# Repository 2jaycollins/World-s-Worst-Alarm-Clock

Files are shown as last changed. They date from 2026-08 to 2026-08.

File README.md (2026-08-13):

# The World's Worst Alarm Clock Ever

An ESP32 alarm clock that keeps perfect time, pulls the weather, works as a Bluetooth speaker, and most importantly, it is very unpredictable.

It is a genuinely good alarm clock. It syncs from NTP, it has a battery-backed RTC so a power cut doesn't touch it, it dims itself at night, and also has forty different ways of ruining your morning.

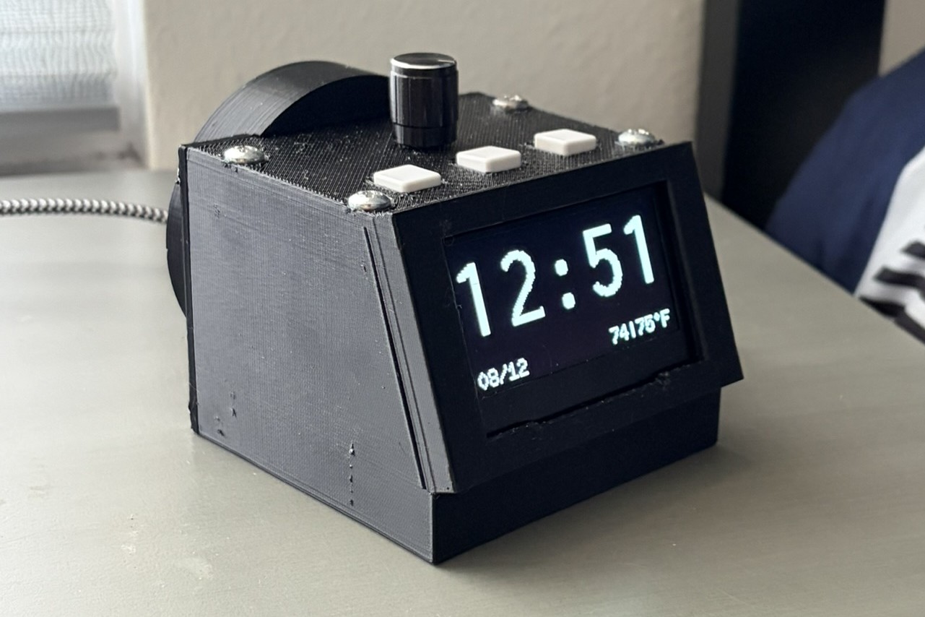
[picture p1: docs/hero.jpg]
The clock on a bedside table


**Demo video:** _(coming soon)_

---

## Why

My roommate needed a new alarm clock, so I took it upon myself to make his life as slightly inconvenient as I could. The problem with a normal alarm is that it works exactly how it is supposed to. Where is the fun in that? This alarm clock is packed with a variety of "features" that do anything from canceling your alarm for no reason to whispering at you in your sleep. 

---

## What it does

**Clock** — Battery-backed DS3231 corrected from NTP at boot. 12/24 hour, date, live temperature. 45 selectable clock fonts, cycled straight from the knob. Automatic night mode dims the panel at a set hour and strips the screen back to just the time. Four brightness levels driven by the SSD1309's real contrast, pre-charge and VCOMH registers, so it goes genuinely dark rather than just dim.

**Weather** — Current temperature and today's high from open-meteo, switching to tomorrow's high in the evening. Multiple saved locations with full POSIX timezone and DST rules; changing location re-syncs both the clock and the forecast. WiFi powers down between refreshes, and a reading that has failed to update several times running is marked stale rather than silently shown as current.

**Alarm** — Set from the menu or armed with one button on the clock face. Plays any WAV or MP3 from the on-board filesystem, and several can be chained into a sequence. The panel flashes while it rings, and a ring pulls the display out of night mode — then puts it back afterwards.

**Bluetooth speaker** — The clock is an A2DP sink. Track title and artist scroll along the bottom and freeze when you pause; the three front buttons become transport controls and the knob is volume. An alarm going off will drop the Bluetooth link, take the audio hardware back, and ring.

Bluetooth mode

---

## The trolls

Forty randomly-triggered events that range from quick visual gags to multi-hour long interruptions.

A troll in action

**Minor** gags are dismissed by any button — a school of fish swims across the clock, a figure paces the screen with footstep audio, the digits scroll too fast to read, the whole clock comes loose and drifts.

**Major** ones freeze the buttons. A firmware update that takes an hour and never finishes. A system error counting down in milliseconds to a reset that never comes. A self-destruct that strobes, detonates, and then leaves you looking at ten full seconds of dead screen wondering whether you've killed it — before the clock crawls back in from off-screen, one element at a time.

**Daily** moods are rolled each morning and last all day: a fish tank in front of the still-working clock, the entire display rotated 180°, or the clock shrunk to a tiny readout with the font control disabled.

**Weather scenes** track the real forecast — drizzle, rain, showers, snow and thunderstorms, each with its own particle density, fall speed, wind slant and animation cadence. When it's raining outside, it rains on your clock.

Storm scene

**Fundamentals** aren't events at all, they're permanent changes in behaviour. The snooze wheel replaces your snooze length with a slot machine. Snooze games make you win a minigame to earn one — lose, and the alarm switches off entirely and has to be re-armed by hand. Alarm drift moves the alarm up to ten minutes either way, re-rolled every time you arm it so the offset can't be learned.

There's a safety switch, accessible by a secret code, that allows the customization of the events and what they are capable of. That's the difference between something you can sleep next to and a science experiment.

---

## Engineering notes

Forty gags share one codebase without turning into forty special cases, mostly because trolls are treated as data rather than code. Each one is a row in a table — kind, duration, whether it draws over the clock, function pointers for its lifecycle hooks. Adding a new troll means an enum entry, a table row, and a draw function; the menu entry, saved on/off state, random scheduling, and input handling come for free. A static_assert catches it if the enum and table ever drift out of sync.

Trolls don't touch the clock state directly. They write to a set of hooks — fake times, per-element pixel offsets, layout flags — that get reset centrally whenever an event ends. That's what stops a cancelled or interrupted troll from leaving the clock in a broken state.

Animation is stateless. Every draw call works out where it is in the sequence as a fraction from 0 to 1 and renders from that alone — nothing increments a frame counter. That means frame rate doesn't matter, there's no state to clean up, and frame 900 renders correctly without stepping through the 899 before it.

Bluetooth and the sound engine fight over the same I2S peripheral, since only one driver can hold it at a time. Switching to speaker mode tears down the sound engine's driver and hands the pins to the A2DP sink; switching back reinstalls it, and an alarm that fires mid-Bluetooth-playback does that handoff live. Getting the Bluetooth stack to fit at all meant giving up the second OTA slot for a custom partition table.

It's a clock, so it has to behave like one even when things go wrong. It comes up on the RTC's last known time if there's no network at boot. Buttons are interrupt-driven with debounce handled in the ISR itself. State transitions are owned by a single file instead of being triggered piecemeal from whatever module wants one. If nobody touches it for a few days, it dims the display and suspends every troll until someone interacts with it again.

Every tunable value — pins, timeouts, night-mode hours, sound files and volumes, per-troll trigger odds, fish swim speed, blink frequency — lives in one config file, so behavior can be adjusted without touching the logic anywhere else.

Designing and printing the case was one of the most time consuming parts of the whole project. The measurements are extremely precise and it took multiple renditions to perfectly narrow down the design. The STL file is shown below.

Stack: C++ on ESP32 / Arduino via PlatformIO · U8g2 · ESP8266Audio · ESP32-A2DP · ArduinoJson · LittleFS · NVS · open-meteo

---

## Hardware

ESP32, SSD1309 128×64 SPI OLED, DS3231 RTC, rotary encoder, three buttons, and a MAX98357A I2S amplifier driving a small speaker.

## Parts list
- [ESP32 dev board](https://www.amazon.com/ESP-WROOM-32-Development-Dual-Mode-Microcontroller-Integrated/dp/B0BK13HWBJ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)
- [SSD1309 2.42" OLED (SPI version)](https://www.aliexpress.us/item/2255799816264653.html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)
- [KY-040 rotary encoder](https://www.aliexpress.us/item/3256807353813379.html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)
- [8Ω speaker](https://www.aliexpress.us/item/3256807619443281.html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)
- [DS3231 RTC module](https://www.aliexpress.us/item/3256805941102171.html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)
- [MAX 98357 amplifier](https://www.amazon.com/dp/B0DPJRLMDJ?ref=ppx_yo2ov_dt_b_fed_asin_title)
- [Buttons](https://www.amazon.com/20pcs-Momentary-Tactile-Button-Switch/dp/B008DGA9UY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)
## Printable enclosure (STL)
Preview on thingiverse (https://www.thingiverse.com/thing:7395218)

-Alternate download:
[STL file](docs/WorstAlarmClockEver.stl)

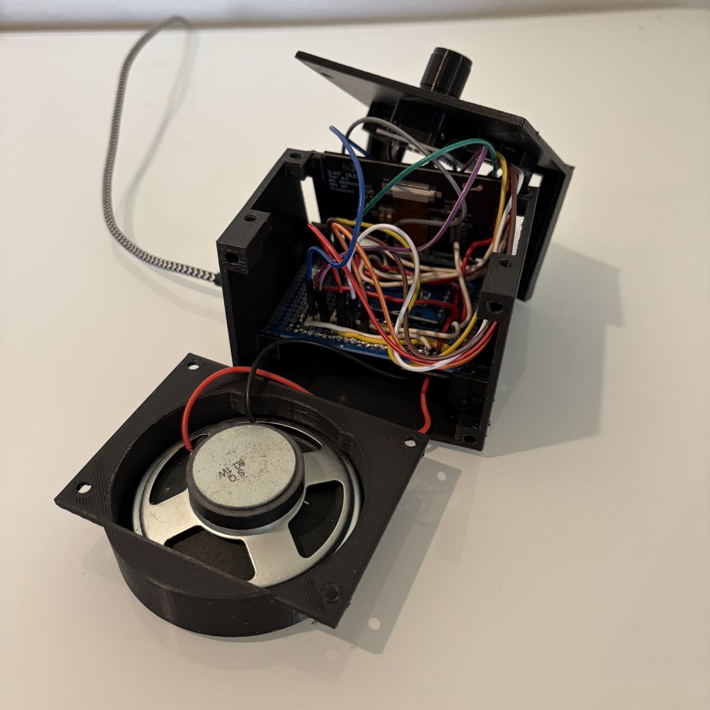
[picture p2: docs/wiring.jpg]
Wiring


---

## Code layout

```
include/values.h          every tunable number, in one place
src/application_code.cpp  main loop and every state transition
src/clock_logic.cpp       timekeeping, WiFi, weather
src/clock.cpp             clock face, brightness, night mode, fonts
src/alarm.cpp             setting, checking and ringing the alarm
src/audio.cpp             WAV/MP3 playback with a play queue
src/menu.cpp              settings, and the hidden troll menu
src/bluetooth.cpp         A2DP speaker mode
src/troll_events.cpp      all forty trolls
src/display.cpp           the panel, plus a time-based animation toolkit
```

Built with [PlatformIO](https://platformio.org/). Copy `include/secretsFILLER.h` to `include/secrets.h` and add your WiFi details before building.

---

Fonts from [U8g2](https://github.com/olikraus/u8g2). Weather from [open-meteo](https://open-meteo.com/). Bluetooth via [ESP32-A2DP](https://github.com/pschatzmann/ESP32-A2DP). Animations built with the [Wokwi animator](https://wokwi.com/animator), icons by [icons8](https://icons8.com/).

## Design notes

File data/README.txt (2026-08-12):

data/  -> LittleFS filesystem image on the ESP32
================================================

Drop your sound files in THIS folder, then upload them to the board with:

    PlatformIO: Project Tasks -> esp32dev -> Platform -> Build Filesystem Image
    PlatformIO: Project Tasks -> esp32dev -> Platform -> Upload Filesystem Image

(or from the CLI:  pio run -t buildfs   then   pio run -t uploadfs )

This is a SEPARATE upload from your normal code upload. Re-run "Upload
Filesystem Image" whenever you add or change a sound.

Play a file from code with a leading slash. The file names all live in
include/values.h -- add yours there rather than hardcoding a path:

    playSound(SND_BEEP);

WAV or MP3?
-----------
Both work. The decoder is picked by the file extension: ".mp3" decodes as MP3,
anything else is treated as WAV.

- WAV is instant, with no decode latency. Use it for short effects: beeps,
  boings, clicks.
- MP3 is far smaller. Use it for anything long: speech, ambience, music.

WAV format requirements (ESP8266Audio AudioGeneratorWAV)
--------------------------------------------------------
- Container : WAV (RIFF), PCM uncompressed (NOT adpcm/float)
- Bit depth : 16-bit (or 8-bit) PCM
- Channels  : mono preferred (output is mono anyway)
- Sample rate: 16000-22050 Hz recommended. 44100 works but is heavier on the
  CPU and on flash space.

Convert anything to a compatible WAV with ffmpeg:

    ffmpeg -i input.mp3 -ac 1 -ar 22050 -sample_fmt s16 beep.wav

...or to a small mono MP3:

    ffmpeg -i input.wav -ac 1 -ar 22050 -b:a 64k output.mp3

Space
-----
The LittleFS partition is 1.875 MB (see partitions_bt.csv). That is a lot of
22 kHz mono audio, but it is not unlimited -- keep an eye on it if you start
adding music.

Output path / hardware
----------------------
Audio leaves the ESP32 over I2S on the pins set in include/values.h
(PIN_AUDIO_DOUT / BCLK / WCLK) into an I2S amplifier. See README.md for wiring.

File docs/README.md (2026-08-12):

# docs/

Screenshots, photos and GIFs for the main README live here. This file is just a
personal reference and isn't linked from the front page.

## Photos and GIFs

Drop the file in this folder, commit it, and reference it from `../README.md`:

    Some alt text

Animated GIFs work exactly the same way and autoplay, which makes them the best
option for showing a troll running. Keep them under a few MB.

## Video

GitHub will **not** play an `.mp4` committed to the repo. Two ways round it:

**1. The drag-and-drop trick (easiest).** Open the repo on github.com, go to the
Issues tab, start a new issue, and drag the video file into the comment box.
Wait for the upload to finish — GitHub inserts a line like
`https://github.com/user-attachments/assets/abc123...`. Copy that line into the
README on its own line and it renders as a playable video. Close the issue
without submitting; the uploaded file stays hosted.

**2. Link to YouTube with a thumbnail.**

    Watch the demo (https://youtu.be/YOUR_VIDEO_ID)

## Current placeholders in the README

Search `README.md` for `docs/` to find them. Replace the filenames with your
own and delete any you don't use.

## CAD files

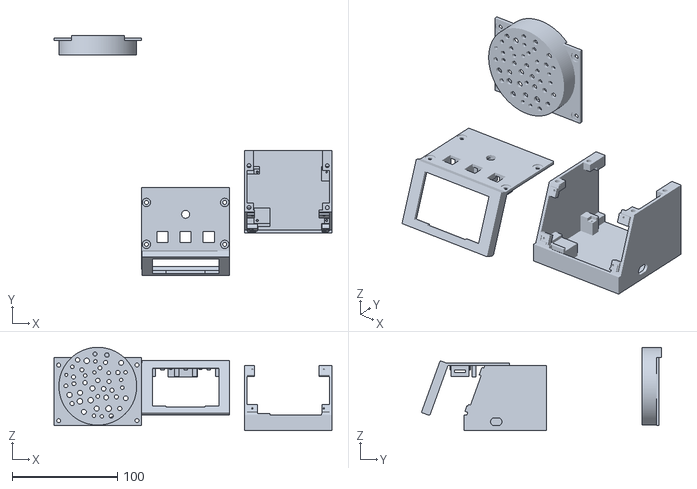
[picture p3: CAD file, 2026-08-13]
docs/WorstAlarmClockEver.stl
264.6 x 228.7 x 79.3

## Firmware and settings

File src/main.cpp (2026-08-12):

// ============================================================================
//  The Worst Alarm Clock
//
//  An ESP32 alarm clock that keeps perfect time, fetches the weather, works as
//  a Bluetooth speaker -- and occasionally lies to you, hides the time, or
//  makes you win a minigame before it will let you snooze.
//
//  Where things live:
//    values.h            every tunable number, in one place
//    clock_logic.cpp     timekeeping, WiFi and weather
//    clock.cpp           the clock face, brightness and night mode
//    alarm.cpp           setting, checking and ringing the alarm
//    audio.cpp           playing sounds off LittleFS
//    menu.cpp            settings, and the hidden troll menu
//    bluetooth.cpp       A2DP speaker mode
//    troll_events.cpp    the trolls themselves
//    application_code.cpp  the main loop and all state transitions
// ============================================================================

#include "application_code.h"

// Bring up the hardware, then the software that depends on it. The order
// matters: the display comes up first so the later steps have somewhere to show
// their progress, and the clock has to know the time before the trolls can
// schedule anything against it.
void setup() {
    Serial.begin(115200);

    setupDisplay();
    loadDisplayPreferences();
    setupEncoder();
    setupClock();          // RTC, WiFi, NTP, first weather fetch
    setupButtons();
    setupAlarm();
    setupTrollEvents();
    setupAudio();

    clockDriftEnabled = trollEnabled(TR_CLOCK_DRIFT);

    DEBUG_PRINTLN("Setup complete");
    DEBUG_PRINTLN("Current time: " + getFormattedTime());

    forceClockRedraw();
    displayClockScreen();
}

void loop() {
    mainLoop();
}

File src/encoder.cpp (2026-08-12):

#include "encoder.h"

static volatile bool encoderPressed = false;
static volatile int  encoderDelta   = 0;
static uint8_t       prevState      = 0;   // last (clk << 1) | dt reading

// Quadrature decode table: [previous state][new state] -> direction. The zeroes
// are the impossible transitions (both pins changing at once), which is how
// electrical noise gets rejected -- it simply produces no movement.
static const int8_t stateTable[4][4] = {
    { 0, -1,  1,  0},
    { 1,  0,  0, -1},
    {-1,  0,  0,  1},
    { 0,  1, -1,  0}
};

// Fires on every edge of either quadrature pin; accumulates signed transitions.
static void IRAM_ATTR encoderRotationISR() {
    uint8_t clk = digitalRead(PIN_ENCODER_CLK);
    uint8_t dt  = digitalRead(PIN_ENCODER_DT);
    uint8_t newState = (clk << 1) | dt;

    if (newState == prevState) return;
    encoderDelta += stateTable[prevState][newState];
    prevState = newState;
}

// Fires on both edges of the push switch. Tracking the debounced logical state
// is what guarantees exactly one press per physical press: without it, bounce on
// RELEASE (after a hold longer than the debounce window) sneaks in a second
// press that latches and fires later, reopening a menu you just closed.
static void IRAM_ATTR encoderButtonISR() {
    static unsigned long lastChange = 0;
    static bool          isDown     = false;

    unsigned long now = millis();
    if (now - lastChange < ENCODER_BTN_DEBOUNCE_MS) return;
    lastChange = now;

    bool down = (digitalRead(PIN_ENCODER_BUTTON) == LOW);
    if (down == isDown) return;
    isDown = down;

    // Ignore a press that arrives mid-rotation -- that is the knob being pushed
    // sideways while turning, not a deliberate click.
    if (down && encoderDelta == 0) encoderPressed = true;
}

// Seed the quadrature state from the pins as they sit, then arm all three
// interrupts on both edges.
void setupEncoder() {
    pinMode(PIN_ENCODER_CLK,    INPUT_PULLUP);
    pinMode(PIN_ENCODER_DT,     INPUT_PULLUP);
    pinMode(PIN_ENCODER_BUTTON, INPUT_PULLUP);

    prevState = (digitalRead(PIN_ENCODER_CLK) << 1) | digitalRead(PIN_ENCODER_DT);

    attachInterrupt(PIN_ENCODER_CLK,    encoderRotationISR, CHANGE);
    attachInterrupt(PIN_ENCODER_DT,     encoderRotationISR, CHANGE);
    attachInterrupt(PIN_ENCODER_BUTTON, encoderButtonISR,   CHANGE);

    DEBUG_PRINTLN("Encoder initialized");
}

// Hand over the accumulated transitions and reset the count.
int getEncoderDelta() {
    int delta = encoderDelta;
    encoderDelta = 0;
    return delta;
}

// Read and clear the push-switch latch.
bool wasEncoderPressed() {
    if (!encoderPressed) return false;
    encoderPressed = false;
    return true;
}

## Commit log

2026-08-12 ESP32 alarm clock with weather, Bluetooth audio and 40 configurable trolls
    [partitions_bt.csv]
2026-08-13 Revise title and include enclosure STL link
    Updated project title and added enclosure design details.
